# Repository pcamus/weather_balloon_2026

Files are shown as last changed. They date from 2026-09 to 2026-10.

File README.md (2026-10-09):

# weather_balloon_2026
This is an update of the [2022 weather_balloon_project](https://github.com/pcamus/weather_balloon_project).

Since the update was requested on very short notice, we built upon the previous version, replacing the processor board with its newer version offering more flash memory.

Due to a lack of time for fine-tuning, we removed the acceleration measurement feature, which had not yielded the expected results because of an too low sampling rate. The objective of these measurements was to compare the balloon's behavior during its liftoff phase against a theoretical model.

To maintain interest in the planned flight, however, we added other measurements that were easy to implement: temperature outside the payload box and battery performance throughout the flight.

So, in summary, our system will measure: the temperature inside and outside the payload box, atmospheric pressure, battery voltage, and the current supplied by the battery. Measurements will be taken every 5 seconds.

The balloon's position over time should be provided by amateur radio operators who will track the balloon (using their own radio module, also carried onboard the payload box). They will also recover our system upon landing (conditions permitting) in order to retrieve the flight data stored in our module.

## Hardware setup.

- A Raspbery Pi Pico 2 (powered by a [RP2350](https://www.raspberrypi.com/products/rp2350/) with 4MB of flash memory).
- A [10-DOF IMU](https://www.waveshare.com/wiki/Pico-10DOF-IMU) from Waveshare.
- A battery module [Pico UPS A](https://www.waveshare.com/wiki/Pico-UPS-A) from Waveshare.
- A waterproof version of the [DS18B20](https://www.analog.com/media/en/technical-documentation/data-sheets/ds18b20.pdf) (-55 to 125 °C) in thermoplastic housing

It should be noted that the 10-DOF IMU board used contains two components: an MPU2950 accelerometer and an LPS22HB temperature and humidity sensor circuit.

In this version, we will not be using the accelerometer.

Care must also be taken as the Waveshare 10-DOF IMU board comes in several versions with different, non-compatible chips. The version used here is Version 2.1.

For the prototype I also use a [Quad GPIO Expander](https://www.waveshare.com/pico-quad-expander.htm) from Waveshare

*The stacked version (wheight = 50 g, DS18B20 sensor not shown) looks like that:*

ballon_stack

Th enclosure files can be found [here](enclosure/README.md)..

## Software.

The programming language is MicroPython. See [software folder](software/README.md).

## Launch and flight.

The balloon and its payload were launched on Sunday, September 27, 2026, at 2:13 PM from IRM site in Uccle, Belgium. 
For the details [see here](flight/README.md).

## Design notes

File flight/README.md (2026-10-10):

# Launch and flight.

The balloon and its payload were launched on Sunday, September 27, 2026, at 2:13 PM from IRM site in Uccle, Belgium.

This flight was proposed as part of the [RMI](https://www.meteo.be/en/about-rmi/introduction)'s 200th anniversary.

irm01

*The RMI launch pad (photo RMI)*

The balloon is inflated with hydrogen and is attached to the parachute (in red), which is then connected to the payload box.
irm02

The payload box used is an expanded polystyrene cooler box.

It contained the payload (90 g) with the outdoor sensor and the radio beacon provided by the radio amateurs, whose call sign was ON7OT-11 (80 g). The total weight was 250 g. 

pod2

pod1

vols ballons IRM

*Flight path (gray line)*

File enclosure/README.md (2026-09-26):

# Enclosure for weather balloon modules.

It's just a box with a lid and some opening to watch heartbeat LED and access power on switch.

wb3dview

Made of PLA, on an Anycubic Kobra Neo : 0.1 mm layer hight, 195°C, tree support for the lid. I used orcaslicer to slice the stl files.

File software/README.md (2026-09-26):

# Python code for weather_balloon_2026

The software is written in Micropython for a Raspberry pi pico

balloon2026_1_0.py is the main file.
The code needs 3 modules for the sensors :
- ds18x20.py for the DS18B20 outdoors temperatutre sensor. This module is part of the MicroPython distribution.
- ina219.py for the battery monitoring
- lps22hb_mod.py for the inside temperature and the atmospheric pressure.

Results are stored in a csv file : balloon_data.csv

The power consumption of the module was measured and is on the order of 140 mWh for an hour. My 3.6V 14450 batteries have a capacity of 3Wh
A file size estimate is 46 kb for an hour.

balloon2026_1_1.py is the next main file. I uses another module for the lps22hb : lps22hb.py

After testing the code with success, I asked Gemini AI to show me some weaknesses and to correct the code

The AI corrected code is balloon2026_1_1_corAI.py and the corrections are explained in [Code_Review_Report_Balloon2026.pdf](Code_Review_Report_Balloon2026.pdf)

The AI was in its turn corrected (wrong object name for lps22hb and useless print to report errors - an improvement will be to add a error log file).
Current stable version is [balloon2026_1_2.py](balloon2026_1_2.py). 

The code was tested during a 6 hours run. Real file size was 154 kb.

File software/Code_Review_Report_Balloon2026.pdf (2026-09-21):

# MicroPython Code Review Report

## Analyzed File: balloon2026_1_1.py | Project: Stratospheric Balloon Payload

Executive Summary: The overall script exhibits a sound functional architecture. However, for a stratospheric flight (extreme low temperatures and power instability hazards), 4 critical program crash risks were identified. This document details these anomalies and provides optimized, flight-ready code.

# 1. Critical Risks & Runtime Errors

Issue / Line | In-Flight Impact | Recommended Fix
Missing DS18B20 Check Lines 50 / 87 | If sensor is disconnected or freezes, id[0] raises an IndexError and crashes the script immediately. | Check if id list is non-empty before reading and wrap in a try...except block.
Duplicated CSV Header Line 74 | In append ('a') mode, any in-flight MCU reboot rewrites the header row in the middle of data. | Check file existence via os.stat() before writing the header.
Busy-Wait Loop Line 102 | The while pass loop burns 100% CPU for 4 seconds, increasing self-heating and draining battery faster. | Replace with dynamic time.sleep_ms() to put the CPU into low-power idle mode.
Cumulative Time Drift Line 105 | Resetting start_time every cycle accumulates execution delays from I2C/Flash I/O operations. | Keep the original mission start_time to compute true elapsed time accurately.

# 2. Engineering Improvements

- Fault Tolerance: Wrapping each sensor read in try...except logs NC (Not Connected) rather than killing the entire mission if an I2C bus temporarily freezes.
- Power Optimization: Switching to passive sleep (`sleep_ms`) during sampling intervals extends battery life on the 14500 cell.
- CSV Sanitization: Removing formatting spaces in text strings ensures seamless automated numeric parsing in spreadsheet tools.

# 3. Recommended MicroPython Code (`balloon2026_1_1_fixed.py`)

### MicroPython Code Analysis — Project Balloon 2026

Confidential — Stratospheric Balloon Mission | Page 1 of 3

# File : balloon2026_1_1_fixed.py

import machine, onewire, ds18x20, time, ina219, lps22hb, os from machine import Pin

PERIOD, DURATION = 5000, 180
FILENAME = "balloon_data.csv"
CORR_PRESS = 1033 / 991
SAMPLES = DURATION // (PERIOD // 1000)

hb = Pin(25, Pin.OUT)
hb.off()

# Initializations

ow = onewire.OneWire(Pin(22)) ds = ds18x20.DS18X20(ow)
ds_roms = ds.scan()

lps = lps22hb.LPS22HB()
bat_mon = ina219.INA219(addr=0x43)

# Verification / creation of CSV file try:

os.stat(FILENAME)
except OSError:
with open(FILENAME, "w") as f: f.write("Time;T_out;T_in;pressure;voltage;current\n")

start_mission_time = time.ticks_ms()
count = 0

while count < SAMPLES:
cycle_start = time.ticks_ms()
hb.on(); time.sleep_ms(50); hb.off()
elapsed_time = time.ticks_diff(cycle_start, start_mission_time) // 1000

# 1. DS18B20 (Outside temperature)

str_T_out = "NC"
if ds_roms:
try:
ds.convert_temp()
time.sleep_ms(750)
str_T_out = f"{ds.read_temp(ds_roms[0]):.1f}".replace('.', ',') except: pass

# 2. LPS22HB & INA219 (Pressure, Inside Temp, Voltage, Current)

try:
str_pressure = f"{lps.pressure * CORR_PRESS:.1f}".replace('.', ',') str_T_in = f"{lps.temperature:.1f}".replace('.', ',')
str_voltage = f"{bat_mon.getBusVoltage_V():.3f}".replace('.', ',') str_current = f"{bat_mon.getCurrent_mA():.3f}".replace('.', ',') except:
str_pressure = str_T_in = str_voltage = str_current = "NC"

# 3. Write to Flash memory

try:
with open(FILENAME, "a") as f: f.write(f"{elapsed_time};{str_T_out};{str_T_in};{str_pressure};{str_voltage};{str_ current}\n")
except: pass

count += 1

# 4. Low-power idle sleep

remaining_sleep = PERIOD - time.ticks_diff(time.ticks_ms(), cycle_start) if remaining_sleep > 0:
time.sleep_ms(remaining_sleep)

hb.on(); time.sleep_ms(2000); hb.off()

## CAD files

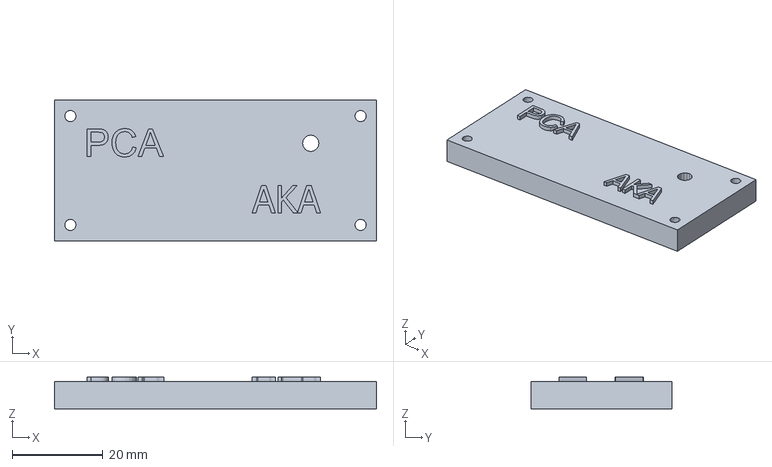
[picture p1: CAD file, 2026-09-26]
enclosure/wb_box2026_lid1.3mf
71.0 x 31.0 x 7.00 mm

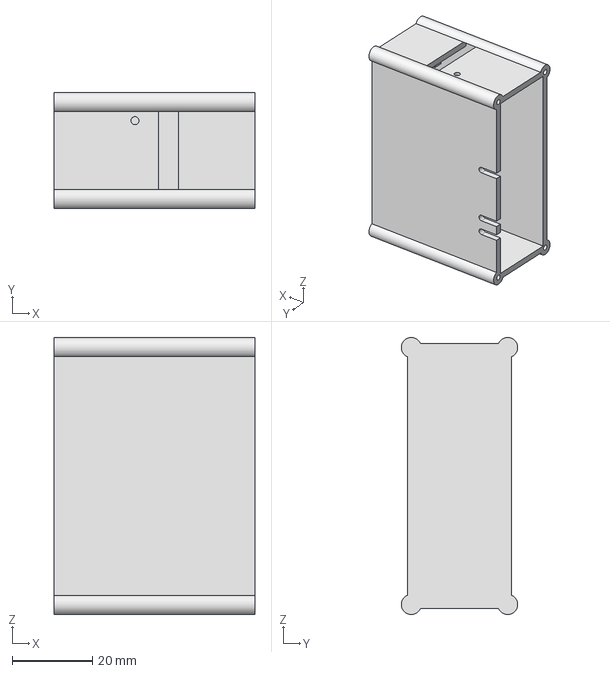
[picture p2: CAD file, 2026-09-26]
enclosure/wb_box2026.stp
50.0 x 29.0 x 69.0 mm

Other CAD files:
enclosure/wb_box2026.stl
enclosure/wb_box2026_lid1.ipt

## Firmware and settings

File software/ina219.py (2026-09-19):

from machine import I2C
import time

# Config Register (R/W)
_REG_CONFIG                 = 0x00
# SHUNT VOLTAGE REGISTER (R)
_REG_SHUNTVOLTAGE           = 0x01

# BUS VOLTAGE REGISTER (R)
_REG_BUSVOLTAGE             = 0x02

# POWER REGISTER (R)
_REG_POWER                  = 0x03

# CURRENT REGISTER (R)
_REG_CURRENT                = 0x04

# CALIBRATION REGISTER (R/W)
_REG_CALIBRATION            = 0x05

class BusVoltageRange:
    """Constants for ``bus_voltage_range``"""
    RANGE_16V               = 0x00      # set bus voltage range to 16V
    RANGE_32V               = 0x01      # set bus voltage range to 32V (default)

class Gain:
    """Constants for ``gain``"""
    DIV_1_40MV              = 0x00      # shunt prog. gain set to  1, 40 mV range
    DIV_2_80MV              = 0x01      # shunt prog. gain set to /2, 80 mV range
    DIV_4_160MV             = 0x02      # shunt prog. gain set to /4, 160 mV range
    DIV_8_320MV             = 0x03      # shunt prog. gain set to /8, 320 mV range

class ADCResolution:
    """Constants for ``bus_adc_resolution`` or ``shunt_adc_resolution``"""
    ADCRES_9BIT_1S          = 0x00      #  9bit,   1 sample,     84us
    ADCRES_10BIT_1S         = 0x01      # 10bit,   1 sample,    148us
    ADCRES_11BIT_1S         = 0x02      # 11 bit,  1 sample,    276us
    ADCRES_12BIT_1S         = 0x03      # 12 bit,  1 sample,    532us
    ADCRES_12BIT_2S         = 0x09      # 12 bit,  2 samples,  1.06ms
    ADCRES_12BIT_4S         = 0x0A      # 12 bit,  4 samples,  2.13ms
    ADCRES_12BIT_8S         = 0x0B      # 12bit,   8 samples,  4.26ms
    ADCRES_12BIT_16S        = 0x0C      # 12bit,  16 samples,  8.51ms
    ADCRES_12BIT_32S        = 0x0D      # 12bit,  32 samples, 17.02ms
    ADCRES_12BIT_64S        = 0x0E      # 12bit,  64 samples, 34.05ms
    ADCRES_12BIT_128S       = 0x0F      # 12bit, 128 samples, 68.10ms

class Mode:
    """Constants for ``mode``"""
    POWERDOW                = 0x00      # power down
    SVOLT_TRIGGERED         = 0x01      # shunt voltage triggered
    BVOLT_TRIGGERED         = 0x02      # bus voltage triggered
    SANDBVOLT_TRIGGERED     = 0x03      # shunt and bus voltage triggered
    ADCOFF                  = 0x04      # ADC off
    SVOLT_CONTINUOUS        = 0x05      # shunt voltage continuous
    BVOLT_CONTINUOUS        = 0x06      # bus voltage continuous
    SANDBVOLT_CONTINUOUS    = 0x07      # shunt and bus voltage continuous
 
class INA219:
    def __init__(self, i2c_bus=1, addr=0x40):
        self.i2c = I2C(i2c_bus);
        self.addr = addr

        # Set chip to known config values to start
        self._cal_value = 0
        self._current_lsb = 0
        self._power_lsb = 0
        self.set_calibration_32V_2A()
        
    def read(self,address):
        data = self.i2c.readfrom_mem(self.addr, address, 2)
        return ((data[0] * 256 ) + data[1])

    def write(self,address,data):
        temp = [0,0]
        temp[1] = data & 0xFF
        temp[0] =(data & 0xFF00) >> 8
        self.i2c.writeto_mem(self.addr,address,bytes(temp))

    def set_calibration_32V_2A(self):
        """Configures to INA219 to be able to measure up to 32V and 2A of current. Counter
           overflow occurs at 3.2A.
           ..note :: These calculations assume a 0.1 shunt ohm resistor is present
        """
        # By default we use a pretty huge range for the input voltage,
        # which probably isn't the most appropriate choice for system
        # that don't use a lot of power.  But all of the calculations
        # are shown below if you want to change the settings.  You will
        # also need to change any relevant register settings, such as
        # setting the VBUS_MAX to 16V instead of 32V, etc.

        # VBUS_MAX = 32V             (Assumes 32V, can also be set to 16V)
        # VSHUNT_MAX = 0.32          (Assumes Gain 8, 320mV, can also be 0.16, 0.08, 0.04)
        # RSHUNT = 0.1               (Resistor value in ohms)

        # 1. Determine max possible current
        # MaxPossible_I = VSHUNT_MAX / RSHUNT
        # MaxPossible_I = 3.2A

        # 2. Determine max expected current
        # MaxExpected_I = 2.0A

        # 3. Calculate possible range of LSBs (Min = 15-bit, Max = 12-bit)
        # MinimumLSB = MaxExpected_I/32767
        # MinimumLSB = 0.000061              (61uA per bit)
        # MaximumLSB = MaxExpected_I/4096
        # MaximumLSB = 0,000488              (488uA per bit)

        # 4. Choose an LSB between the min and max values
        #    (Preferrably a roundish number close to MinLSB)
        # CurrentLSB = 0.0001 (100uA per bit)
        self._current_lsb = 1  # Current LSB = 100uA per bit

        # 5. Compute the calibration register
        # Cal = trunc (0.04096 / (Current_LSB * RSHUNT))
        # Cal = 4096 (0x1000)

        self._cal_value = 4096

        # 6. Calculate the power LSB
        # PowerLSB = 20 * CurrentLSB
        # PowerLSB = 0.002 (2mW per bit)
        self._power_lsb = .002  # Power LSB = 2mW per bit

        # 7. Compute the maximum current and shunt voltage values before overflow
        #
        # Max_Current = Current_LSB * 32767
        # Max_Current = 3.2767A before overflow
        #
        # If Max_Current > Max_Possible_I then
        #    Max_Current_Before_Overflow = MaxPossible_I
        # Else
        #    Max_Current_Before_Overflow = Max_Current
        # End If
        #
        # Max_ShuntVoltage = Max_Current_Before_Overflow * RSHUNT
        # Max_ShuntVoltage = 0.32V
        #
        # If Max_ShuntVoltage >= VSHUNT_MAX
        #    Max_ShuntVoltage_Before_Overflow = VSHUNT_MAX
        # Else
        #    Max_ShuntVoltage_Before_Overflow = Max_ShuntVoltage
        # End If

        # 8. Compute the Maximum Power
        # MaximumPower = Max_Current_Before_Overflow * VBUS_MAX
        # MaximumPower = 3.2 * 32V
        # MaximumPower = 102.4W

        # Set Calibration register to 'Cal' calculated above
        self.write(_REG_CALIBRATION,self._cal_value)
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

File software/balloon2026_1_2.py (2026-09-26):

# File : balloon2026_1_2.py
#
# This version only uses LPS22HB chip on the Pico 10-DOF IMU module
# Acceleratio is not recorded in this version.
#
# Log the temperature inside and outside the payload box, atmospheric pressure,
# battery voltage, and the current supplied by the battery
# Takes samples each 5 seconds
# Repeat the process during a specified time
#
# Append the data to csv file.
# Size : each period -> max 64 bytes. For 5s period -> 1 hour recording = 46080 bytes
#
# Power consumption 140 mWh per hour. Battery model 14500 = 2960 mWh -> +/- 20h of battery life
#
# Code was reviewed by Gemini AI and amended to increase reliability
# info@pcamus.be
# 24/09/2026

import machine
from machine import Pin
import onewire
import ds18x20
import time
import ina219
import lps22hb
import os

# -----------------------------------------------------------------------------
# General parameters
# -----------------------------------------------------------------------------
PERIOD = 5000         # sampling rate (in ms)
DURATION = 21600   # 21600 = 6 hour - total acquisition time (in seconds)
FILENAME = "balloon_data.csv"
CORR_PRESS = 1033/991  # calibration with IRM data

SAMPLES = DURATION // (PERIOD//1000)
print (SAMPLES)

# -----------------------------------------------------------------------------
# Heart beat and status LED
# -----------------------------------------------------------------------------
hb = Pin(25, Pin.OUT)
hb.off()

# -----------------------------------------------------------------------------
# DS18B20 initialization : temperature outside the payload
# ----------------------------------------------------------------------------
PIN_DATA = 22
ow = onewire.OneWire(Pin(PIN_DATA))
ds = ds18x20.DS18X20(ow)

ds_roms = ds.scan()

# --------------------------------------------------------------------------------
# LPS22HB initialization : atmospheric pressure and temperature inside the payload
# --------------------------------------------------------------------------------

lps22hb=lps22hb.LPS22HB() # uses I2C1

# --------------------------------------------------------------------------------
# INA219 initialization : battery voltage and current
# --------------------------------------------------------------------------------

bat_mon = ina219.INA219(addr=0x43) # uses I2C1

# Two blinks means all initializations succeeded
hb.on() 
time.sleep_ms(1000)
hb.off()
time.sleep_ms(1000)
hb.on() 
time.sleep_ms(1000)
hb.off()

# -----------------------------------------------------------------------------
# Opening and possible creation of data file on the flash - append mode
# First, write a header text for each column
# file will be formated as CSV
# ----------------------------------------------------------------------------
file_exists = True
try:
    os.stat(FILENAME)
except OSError:
    file_exists = False

if not file_exists:  # write column header if new file
    with open(FILENAME, "w") as f:
        f.write("Time;T_out;T_in;pressure;voltage;current\n")

# -----------------------------------------------------------------------------
# Main loop
# -----------------------------------------------------------------------------
start_mission_time = time.ticks_ms()
count = 0

while count < SAMPLES:
    cycle_start = time.ticks_ms()
    
    # LED fast flash  (Heartbeat)
    hb.on()
    time.sleep_ms(50)
    hb.off()
    
    # Elapsed time since the start of the mission
    elapsed_time = time.ticks_diff(cycle_start, start_mission_time) // 1000

    # call to DS18B20 sensor 
    str_T_out = "NC"
    if ds_roms:
        try:
            ds.convert_temp()
            time.sleep_ms(750)  # must wait a little lesss than 750 ms for 12-bit conversion
            T_out = ds.read_temp(ds_roms[0])
            str_T_out = f"{T_out:.1f}".replace('.', ',')
        except Exception as e:
            pass

    # call to LPS22HB chip (for inside temperature and pressure)
    try:
        pressure = lps22hb.pressure * CORR_PRESS
        T_in = lps22hb.temperature
        str_T_in = f"{T_in:.1f}".replace('.', ',')
        str_pressure = f"{pressure:.1f}".replace('.', ',')
    except Exception as e:
        str_T_in, str_pressure = "NC", "NC"
        

    # call to ina219 chip (for battery voltage and current)
    try:
        voltage = bat_mon.getBusVoltage_V()
        current = bat_mon.getCurrent_mA()
        str_voltage = f"{voltage:.3f}".replace('.', ',')
        str_current = f"{current:.3f}".replace('.', ',')
    except Exception as e:
        str_voltage, str_current = "NC", "NC"
        pass

    # Record data on flash memory
    try:
        with open(FILENAME, "a") as f:
            f.write(f"{elapsed_time};{str_T_out};{str_T_in};{str_pressure};{str_voltage};{str_current}\n")
    except OSError as e:
        pass

    count += 1

    # Compute remaining time to reach sample period
    elapsed_in_cycle = time.ticks_diff(time.ticks_ms(), cycle_start)
    remaining_sleep = PERIOD - elapsed_in_cycle
    
    if remaining_sleep > 0: # and sleep for the remaining time
        time.sleep_ms(remaining_sleep)

# Signal de fin (LED allumée 2 secondes)
hb.on()
time.sleep_ms(2000)
hb.off()
